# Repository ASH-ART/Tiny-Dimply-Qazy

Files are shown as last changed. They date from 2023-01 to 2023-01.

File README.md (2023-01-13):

# Tiny Dimply Qazy

A 10.5u 35% keyboard PCB. A tribute to Lazydesigner's Dimple, and tominabox1 and whydobearsexplod's QAZ.

## Status
WIP; awaiting second round of prototyping.

## Layout
KLE preview
<a href="http://www.keyboard-layout-editor.com/#/gists/85e2e431b75c7d8e9e7332ab9f5636bb">Link<a>
  
## Renders
Top view
Bottom view

## Specs
* STM32 F072 MCU
* JST SH or Molex EZMate Pico headers
* ESD and overcurrent protection
* Meme cut
* Other stuff like diodes (the cool ones)

## Todo
- [x] Confirm prototype works electronically
- [ ] QoL improvements and case fit
- [ ] Generic silk with revision number
- [ ] Misc. cleanups
- [ ] A la carte gerbers for connector options (JST or EZMate)
- [ ] Use git submodule for parts lib

## Disclaimer

This PCB has been tested to work _electronically_, but requires further prototyping for fit and usability. The members of the PCB development team are not liable if you end up with a non-functional pcb. Order at your own risk. Support will not be provided but pull requests will be reviewed and possibly accepted.

## License

This project is released under the GPL v3 License. Please refer to the LICENCE file.
  
## Credits
  
PeppyToad for the layout and pcb help and firmware, ash for the scuffed pcb, lazydesigner, tominabox1, whydobearsexplod and Alas for the inspiration.
Consider bhj

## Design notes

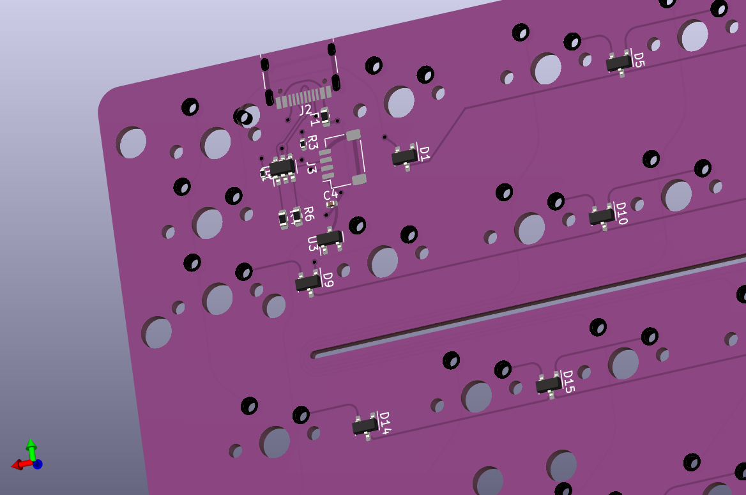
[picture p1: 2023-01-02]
Exports/Tiny Dimply Qazy PCB Render.png

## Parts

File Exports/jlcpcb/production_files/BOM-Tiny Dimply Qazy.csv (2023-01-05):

Comment | Designator | Footprint | LCSC
Polyfuse_Small | F1 | Fuse_0603_1608Metric | C10677
SMF9.0CA | D_PWR1 | D_SOD-123 | C123799
100n | C_VDD1,C_VDDIO2 | C_0603_1608Metric | C14663
1u | C_VDDA2 | C_0603_1608Metric | C15849
4.7u | C_VDD2,C_VDDIO1 | C_0603_1608Metric | C19666
10u | C_VDDA1 | C_0603_1608Metric | C19702
1.5k | R_USB1 | R_0603_1608Metric | C22843
4.7uF | C1 | C_0402_1005Metric | C23733
BAV70 | D1,D10,D11,D12,D13,D14,D15,D16,D17,D18,D19,D2,D20,D3,D4,D5,D6,D7,D8,D9 | SOT-23 | C2501
100k | R2 | R_0402_1005Metric | C25741
10k | R1,R3 | R_0402_1005Metric | C25744
USB_C_Receptacle_USB2.0 | J2 | USB_C_Receptacle_HRO_TYPE-C-31-M-12 | C2765186
USBLC6-2SC6 | U3 | SOT-23-6 | C2827654
Conn_01x04_Male | J1 | JST_SH_SM04B-SRSS-TB_1x04-1MP_P1.00mm_Horizontal | C2845363
B/R | SW1 | SW_SPST_TL3342 | C318884
470nF | C2 | C_0402_1005Metric | C47339
1uF | C3,C4 | C_0402_1005Metric | C52923
XC6206PxxxMR-Regulator_Linear | U2 | SOT-23 | C5446
Conn_01x04_Male | J3 | Molex_Pico-EZmate_78171-0004_1x04-1MP_P1.20mm_Vertical | C588524
STM32F072CBTx | U1 | LQFP-48_7x7mm_P0.5mm | C81720
5k1 | R4,R5 | R_0603_1608Metric | C83063
2N7002 | Q1 | SOT-23 | C8545
MX-NoLED | MX22 | MXOnly-1U-NoLED
MX-NoLED | MX39 | MXOnly-1.5U-NoLED
MX-NoLED | MX33 | MXOnly-1U-NoLED
MX-NoLED | MX20 | MXOnly-6U-Centered-ReversedStabilizers-NoLED
MX-NoLED | MX29 | MXOnly-1U-NoLED
MX-NoLED | MX25 | MXOnly-1.75U-NoLED
MX-NoLED | MX23 | MXOnly-1U-NoLED
MX-NoLED | MX43 | MXOnly-1.25U-NoLED
MX-NoLED | MX1 | MXOnly-1.5U-NoLED
MX-NoLED | MX6 | MXOnly-1U-NoLED
MX-NoLED | MX3 | MXOnly-1U-NoLED
MX-NoLED | MX31 | MXOnly-1U-NoLED
MX-NoLED | MX14 | MXOnly-3U-ReversedStabilizers-NoLED
MX-NoLED | MX40 | MXOnly-1U-NoLED
MX-NoLED | MX5 | MXOnly-1.75U-NoLED
MX-NoLED | MX24 | MXOnly-3U-ReversedStabilizers-NoLED
MX-NoLED | MX9 | MXOnly-1.25U-NoLED
MX-NoLED | MX37 | MXOnly-1U-NoLED
MX-NoLED | MX19 | MXOnly-7U-ReversedStabilizers-NoLED
MX-NoLED | MX16 | MXOnly-1U-NoLED
MX-NoLED | MX38 | MXOnly-1U-NoLED
MX-NoLED | MX17 | MXOnly-1U-NoLED
MX-NoLED | MX12 | MXOnly-1U-NoLED
MX-NoLED | MX34 | MXOnly-1U-NoLED
MX-NoLED | MX36 | MXOnly-1.25U-NoLED
MX-NoLED | MX30 | MXOnly-1U-NoLED
MX-NoLED | MX41 | MXOnly-1.5U-NoLED
MX-NoLED | MX11 | MXOnly-1U-NoLED
MX-NoLED | MX13 | MXOnly-1.25U-NoLED
MX-NoLED | MX15 | MXOnly-1.75U-NoLED
MX-NoLED | MX28 | MXOnly-1U-NoLED
MX-NoLED | MX21 | MXOnly-1U-NoLED
MX-NoLED | MX35 | MXOnly-1U-NoLED
MX-NoLED | MX2 | MXOnly-1U-NoLED
MX-NoLED | MX7 | MXOnly-1U-NoLED
MX-NoLED | MX44 | MXOnly-1.75U-NoLED
MX-NoLED | MX42 | MXOnly-ISO
MX-NoLED | MX32 | MXOnly-1U-NoLED
MX-NoLED | MX18 | MXOnly-1U-NoLED
MX-NoLED | MX10 | MXOnly-1U-NoLED
MX-NoLED | MX8 | MXOnly-1U-NoLED
MX-NoLED | MX4 | MXOnly-1.25U-NoLED
MX-NoLED | MX26 | MXOnly-1U-NoLED
MX-NoLED | MX27 | MXOnly-1U-NoLED

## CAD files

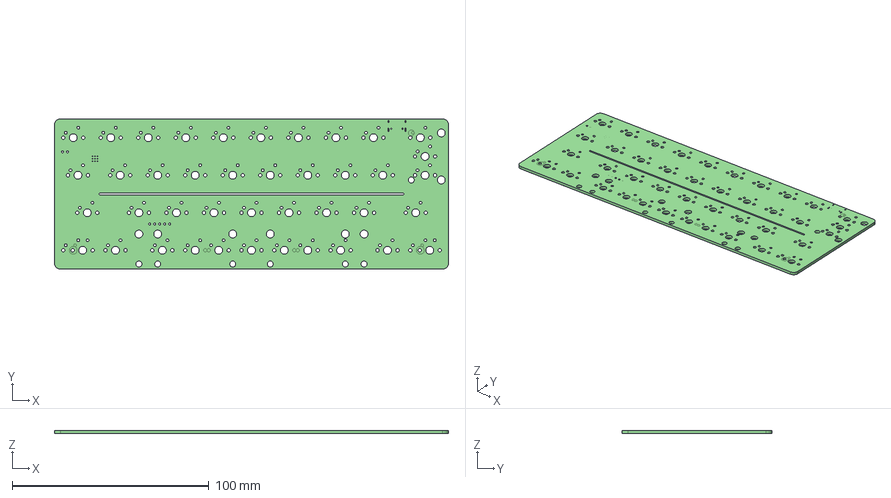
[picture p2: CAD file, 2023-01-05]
Exports/Tiny Dimply Qazy STEP Export.step
200.0 x 76.2 x 1.60 mm

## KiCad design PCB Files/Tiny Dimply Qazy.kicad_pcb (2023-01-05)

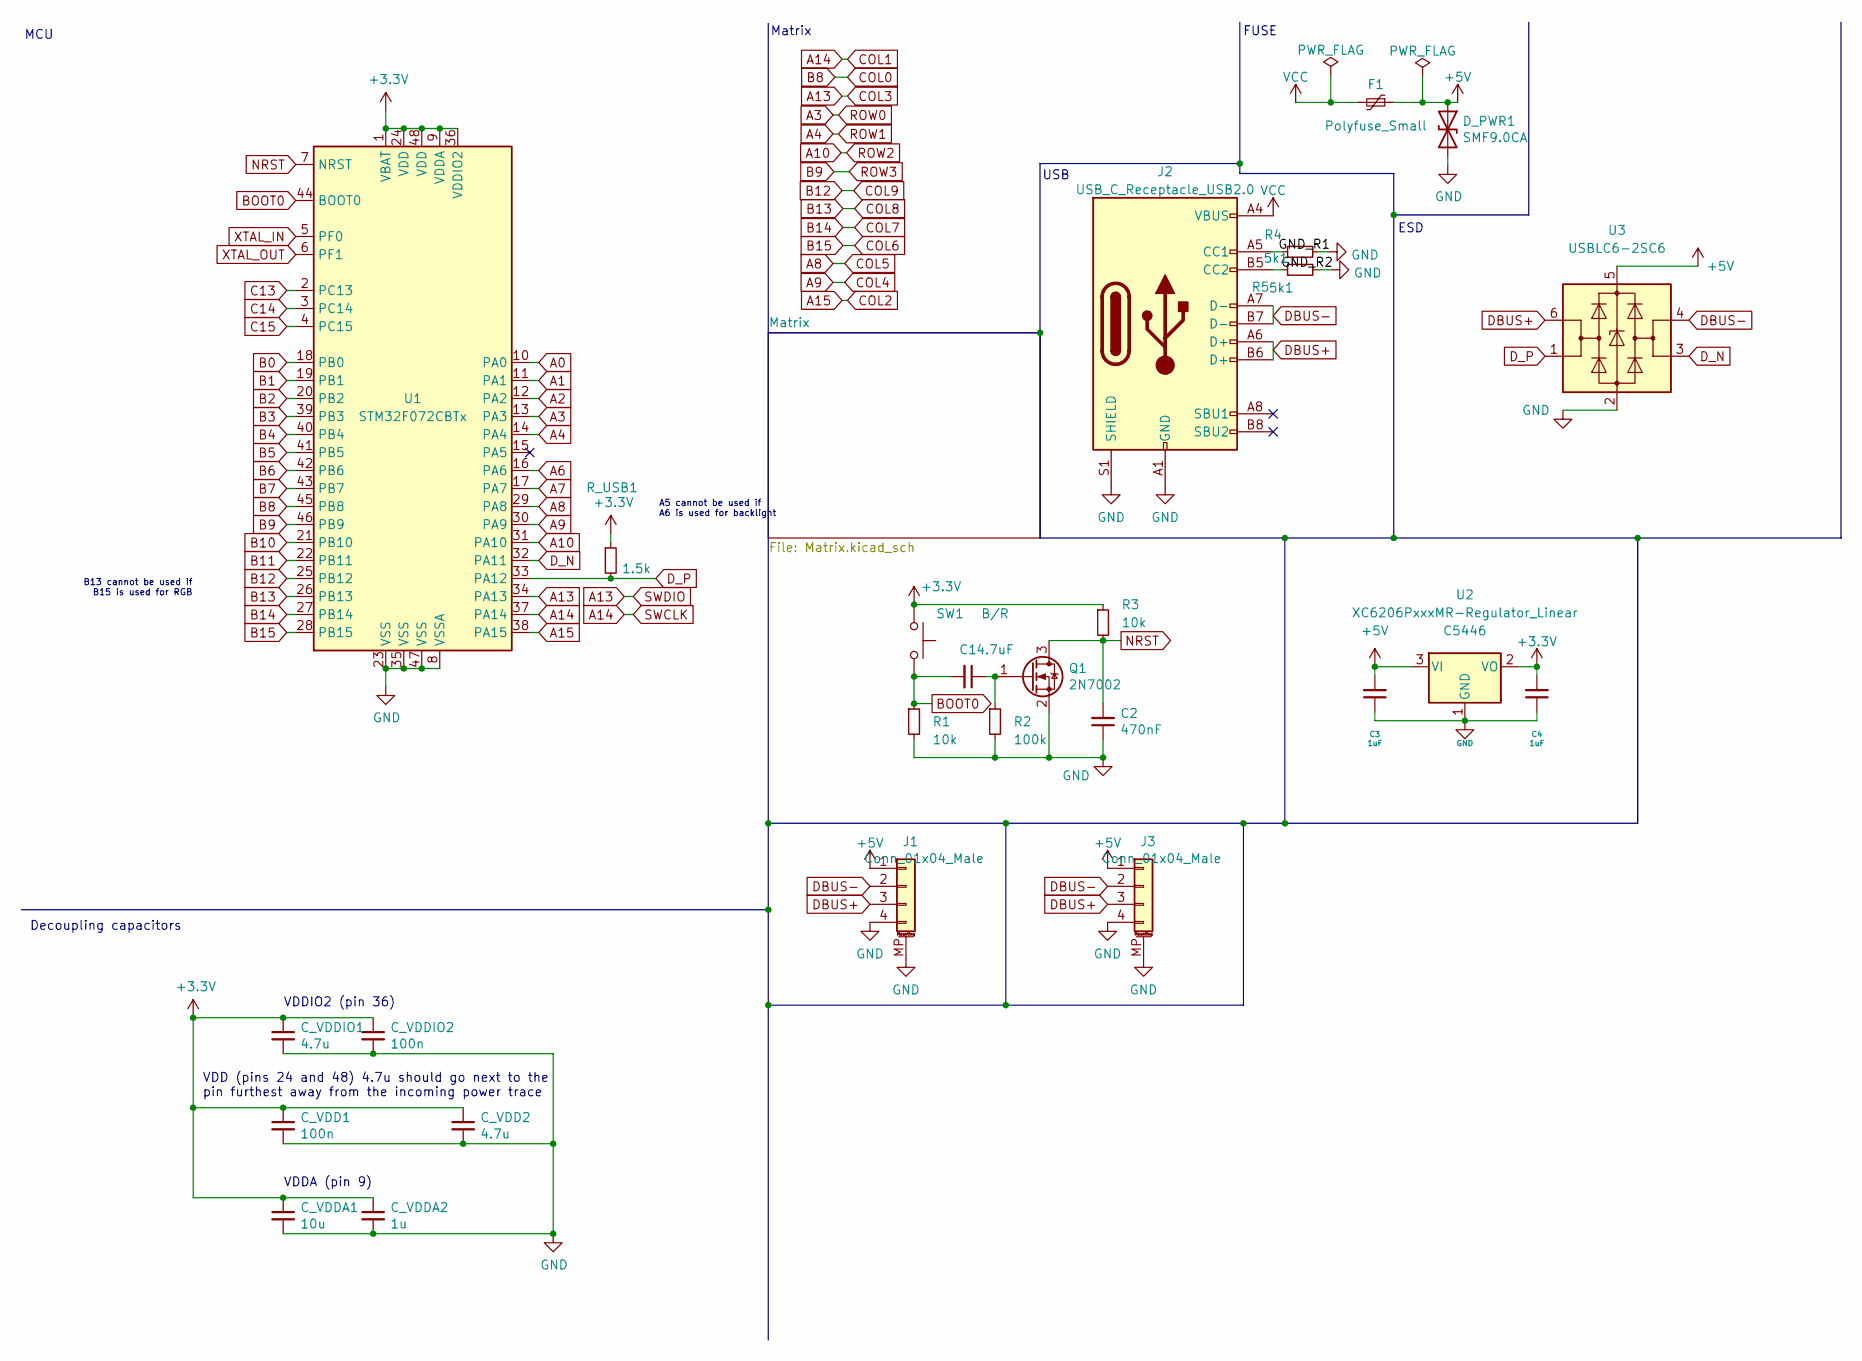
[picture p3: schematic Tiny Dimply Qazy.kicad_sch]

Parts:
C1: 4.7uF; C_0402_1005Metric; LCSC C23733
C2: 470nF; C_0402_1005Metric; LCSC C47339
C3, C4: 1uF; C_0402_1005Metric; LCSC C52923
C_VDD1: 100n; C_0603_1608Metric
C_VDD2: 4.7u; C_0603_1608Metric
C_VDDA1: 10u; C_0603_1608Metric
C_VDDA2: 1u; C_0603_1608Metric
C_VDDIO1: 4.7u; C_0603_1608Metric
C_VDDIO2: 100n; C_0603_1608Metric
D_PWR1: SMF9.0CA; D_SOD-123
F1: Polyfuse_Small; Fuse_0603_1608Metric
J1: Conn_01x04_Male; JST_SH_SM04B-SRSS-TB_1x04-1MP_P1.00mm_Horizontal
J2: USB_C_Receptacle_USB2.0; USB_C_Receptacle_HRO_TYPE-C-31-M-12
J3: Conn_01x04_Male; Molex_Pico-EZmate_78171-0004_1x04-1MP_P1.20mm_Vertical
Q1: 2N7002; SOT-23; LCSC C8545
R1, R3: 10k; R_0402_1005Metric; LCSC C25744
R2: 100k; R_0402_1005Metric; LCSC C25741
R4, R5: 5k1; R_0603_1608Metric
R_USB1: 1.5k; R_0603_1608Metric
SW1: B/R; SW_SPST_TL3342; LCSC C318884
U1: STM32F072CBTx; LQFP-48_7x7mm_P0.5mm
U2: XC6206PxxxMR-Regulator_Linear; SOT-23; LCSC C5446
U3: USBLC6-2SC6; SOT-23-6; LCSC C2827654

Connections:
+3V3: C4.2, C_VDD1.1, C_VDD2.1, C_VDDA1.1, C_VDDA2.1, C_VDDIO1.1, C_VDDIO2.1, R3.1, R_USB1.1, SW1.1, U1.1 (VBAT), U1.9 (VDDA), U1.24 (VDD), U1.36 (VDDIO2), U1.48 (VDD), U2.2 (VO)
+5V: C3.2, D_PWR1.1 (A1), F1.1, J1.1, J3.1, U2.3 (VI), U3.5 (VBUS)
/GND_R1: J2.A5 (CC1), R4.1
/GND_R2: J2.B5 (CC2), R5.1
A0: U1.10 (PA0)
A1: U1.11 (PA1)
A2: U1.12 (PA2)
A3: U1.13 (PA3); also elsewhere on the board
A4: U1.14 (PA4); also elsewhere on the board
A6: U1.16 (PA6)
A7: U1.17 (PA7)
A8: U1.29 (PA8); also elsewhere on the board
A9: U1.30 (PA9); also elsewhere on the board
A10: U1.31 (PA10); also elsewhere on the board
A13: U1.34 (PA13); also elsewhere on the board
A14: U1.37 (PA14); also elsewhere on the board
A15: U1.38 (PA15); also elsewhere on the board
B0: U1.18 (PB0)
B1: U1.19 (PB1)
B2: U1.20 (PB2)
B3: U1.39 (PB3)
B4: U1.40 (PB4)
B5: U1.41 (PB5)
B6: U1.42 (PB6)
B7: U1.43 (PB7)
B8: U1.45 (PB8); also elsewhere on the board
B9: U1.46 (PB9); also elsewhere on the board
B10: U1.21 (PB10)
B11: U1.22 (PB11)
B12: U1.25 (PB12); also elsewhere on the board
B13: U1.26 (PB13); also elsewhere on the board
B14: U1.27 (PB14); also elsewhere on the board
B15: U1.28 (PB15); also elsewhere on the board
BOOT0: C1.2, R1.1, SW1.2, U1.44 (BOOT0)
C13: U1.2 (PC13)
C14: U1.3 (PC14)
C15: U1.4 (PC15)
DBUS+: J1.3, J2.A6 (D+), J2.B6 (D+), J3.3, U3.6 (I/O1)
DBUS-: J1.2, J2.A7 (D-), J2.B7 (D-), J3.2, U3.4 (I/O2)
D_N: U1.32 (PA11), U3.3 (I/O2)
D_P: R_USB1.2, U1.33 (PA12), U3.1 (I/O1)
unnamed: C1.1, Q1.1 (G), R2.1
VCC: F1.2, J2.A4 (VBUS), J2.A9 (VBUS), J2.B4 (VBUS), J2.B9 (VBUS)
XTAL_IN: U1.5 (PF0)
XTAL_OUT: U1.6 (PF1)

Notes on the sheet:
A5 cannot be used if A6 is used for backlight
Decoupling capacitors
VDDIO2 (pin 36)
Matrix
USB
FUSE
MCU
ESD
B13 cannot be used if B15 is used for RGB
VDDA (pin 9)
VDD (pins 24 and 48) 4.7u should go next to the pin furthest away from the incoming power trace

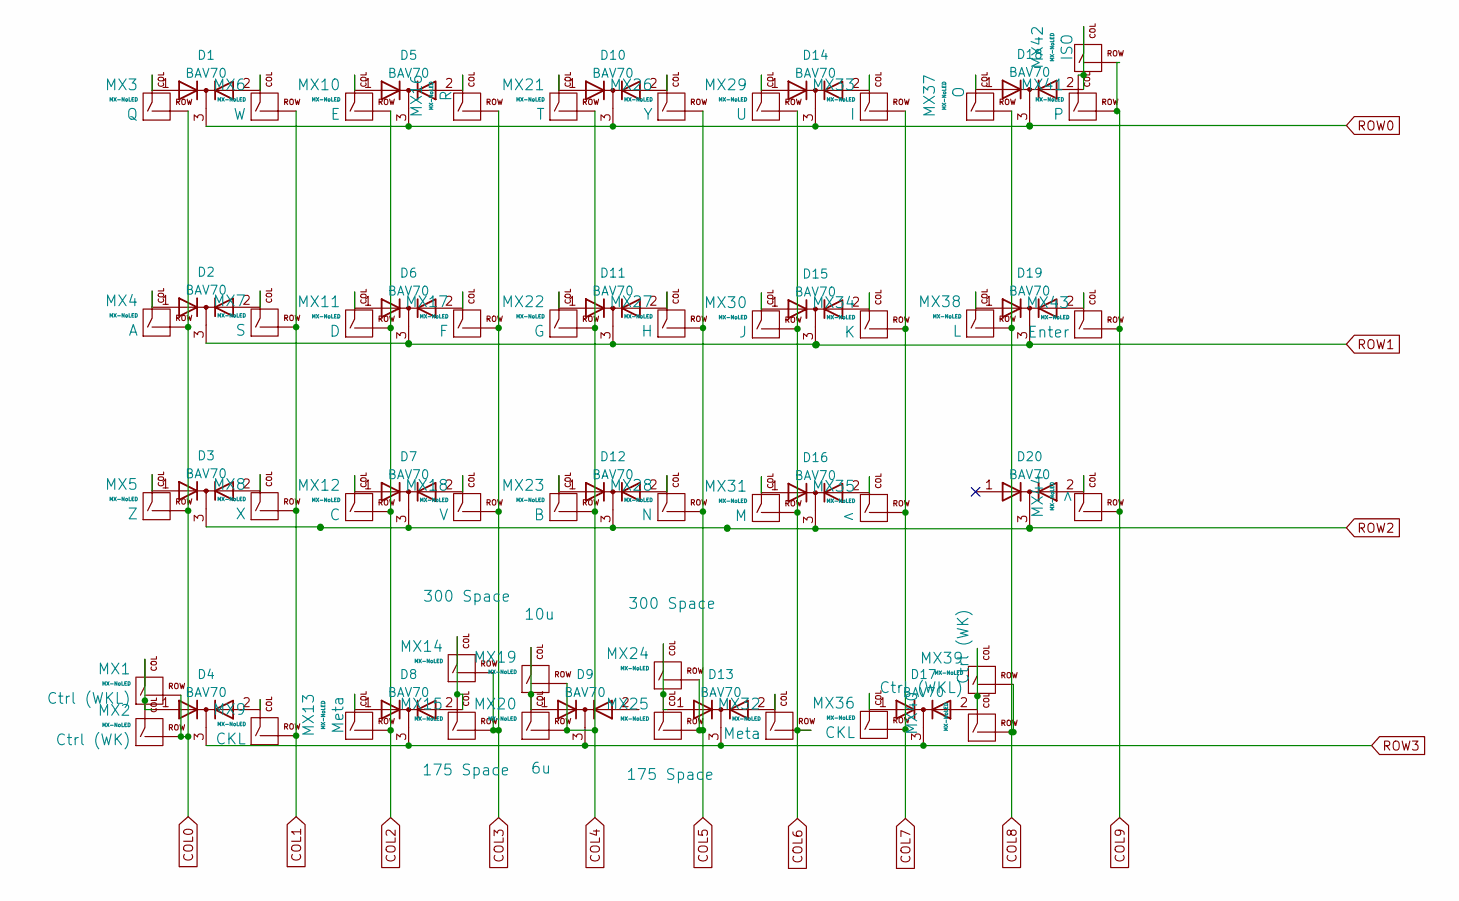
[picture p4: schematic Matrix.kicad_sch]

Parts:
D1, D2, D3, D4, D5, D6, D7, D8, D9, D10, D11, D12, D13, D14, D15, D16, D17, D18, D19, D20: BAV70; SOT-23
MX1, MX39, MX41: MX-NoLED; MXOnly-1.5U-NoLED
MX2, MX3, MX6, MX7, MX8, MX10, MX11, MX12, MX16, MX17, MX18, MX21, MX22, MX23, MX26, MX27, MX28, MX29, MX30, MX31, MX33, MX34, MX35, MX37, MX38, MX40: MX-NoLED; MXOnly-1U-NoLED
MX4, MX9, MX13, MX32, MX36, MX43: MX-NoLED; MXOnly-1.25U-NoLED
MX5, MX15, MX25, MX44: MX-NoLED; MXOnly-1.75U-NoLED
MX14, MX24: MX-NoLED; MXOnly-3U-ReversedStabilizers-NoLED
MX19: MX-NoLED; MXOnly-7U-ReversedStabilizers-NoLED
MX20: MX-NoLED; MXOnly-6U-Centered-ReversedStabilizers-NoLED
MX42: MX-NoLED; MXOnly-ISO

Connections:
A3: D1.3 (K), D5.3 (K), D10.3 (K), D14.3 (K), D18.3 (K); also elsewhere on the board
A4: D2.3 (K), D6.3 (K), D11.3 (K), D15.3 (K), D19.3 (K); also elsewhere on the board
A8: MX24.2 (ROW), MX25.2 (ROW), MX26.2 (ROW), MX27.2 (ROW), MX28.2 (ROW); also elsewhere on the board
A9: MX19.2 (ROW), MX20.2 (ROW), MX21.2 (ROW), MX22.2 (ROW), MX23.2 (ROW); also elsewhere on the board
A10: D3.3 (K), D7.3 (K), D12.3 (K), D16.3 (K), D20.3 (K); also elsewhere on the board
A13: MX14.2 (ROW), MX15.2 (ROW), MX16.2 (ROW), MX17.2 (ROW), MX18.2 (ROW); also elsewhere on the board
A14: MX6.2 (ROW), MX7.2 (ROW), MX8.2 (ROW), MX9.2 (ROW); also elsewhere on the board
A15: MX10.2 (ROW), MX11.2 (ROW), MX12.2 (ROW), MX13.2 (ROW); also elsewhere on the board
B8: MX1.2 (ROW), MX2.2 (ROW), MX3.2 (ROW), MX4.2 (ROW), MX5.2 (ROW); also elsewhere on the board
B9: D4.3 (K), D8.3 (K), D9.3 (K), D13.3 (K), D17.3 (K); also elsewhere on the board
B12: MX41.2 (ROW), MX42.2 (ROW), MX43.2 (ROW), MX44.2 (ROW); also elsewhere on the board
B13: MX37.2 (ROW), MX38.2 (ROW), MX39.2 (ROW), MX40.2 (ROW); also elsewhere on the board
B14: MX33.2 (ROW), MX34.2 (ROW), MX35.2 (ROW), MX36.2 (ROW); also elsewhere on the board
B15: MX29.2 (ROW), MX30.2 (ROW), MX31.2 (ROW), MX32.2 (ROW); also elsewhere on the board
unnamed: D1.1 (A), MX3.1 (COL)
unnamed: D1.2 (A), MX6.1 (COL)
unnamed: D2.1 (A), MX4.1 (COL)
unnamed: D2.2 (A), MX7.1 (COL)
unnamed: D3.1 (A), MX5.1 (COL)
unnamed: D3.2 (A), MX8.1 (COL)
unnamed: D4.1 (A), MX1.1 (COL), MX2.1 (COL)
unnamed: D4.2 (A), MX9.1 (COL)
unnamed: D5.1 (A), MX10.1 (COL)
unnamed: D5.2 (A), MX16.1 (COL)
unnamed: D6.1 (A), MX11.1 (COL)
unnamed: D6.2 (A), MX17.1 (COL)
unnamed: D7.1 (A), MX12.1 (COL)
unnamed: D7.2 (A), MX18.1 (COL)
unnamed: D8.1 (A), MX13.1 (COL)
unnamed: D8.2 (A), MX14.1 (COL), MX15.1 (COL)
unnamed: D9.1 (A), MX19.1 (COL), MX20.1 (COL)
unnamed: D10.1 (A), MX21.1 (COL)
unnamed: D10.2 (A), MX26.1 (COL)
unnamed: D11.1 (A), MX22.1 (COL)
unnamed: D11.2 (A), MX27.1 (COL)
unnamed: D12.1 (A), MX23.1 (COL)
unnamed: D12.2 (A), MX28.1 (COL)
unnamed: D13.1 (A), MX24.1 (COL), MX25.1 (COL)
unnamed: D13.2 (A), MX32.1 (COL)
unnamed: D14.1 (A), MX29.1 (COL)
unnamed: D14.2 (A), MX33.1 (COL)
unnamed: D15.1 (A), MX30.1 (COL)
unnamed: D15.2 (A), MX34.1 (COL)
unnamed: D16.1 (A), MX31.1 (COL)
unnamed: D16.2 (A), MX35.1 (COL)
unnamed: D17.1 (A), MX36.1 (COL)
unnamed: D17.2 (A), MX39.1 (COL), MX40.1 (COL)
unnamed: D18.1 (A), MX37.1 (COL)
unnamed: D18.2 (A), MX41.1 (COL), MX42.1 (COL)
unnamed: D19.1 (A), MX38.1 (COL)
unnamed: D19.2 (A), MX43.1 (COL)
unnamed: D20.2 (A), MX44.1 (COL)

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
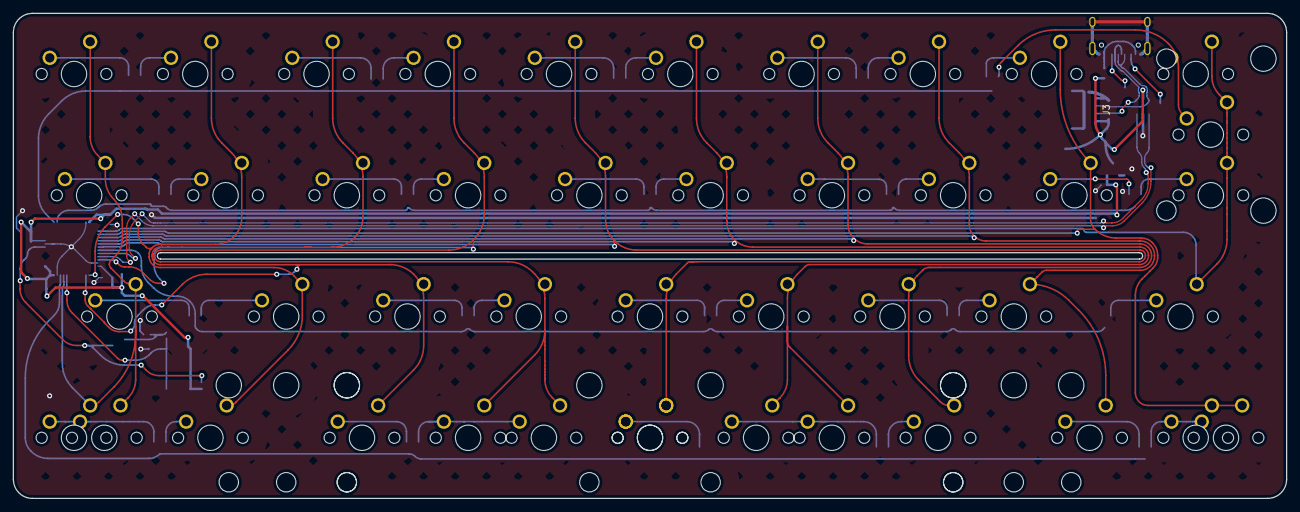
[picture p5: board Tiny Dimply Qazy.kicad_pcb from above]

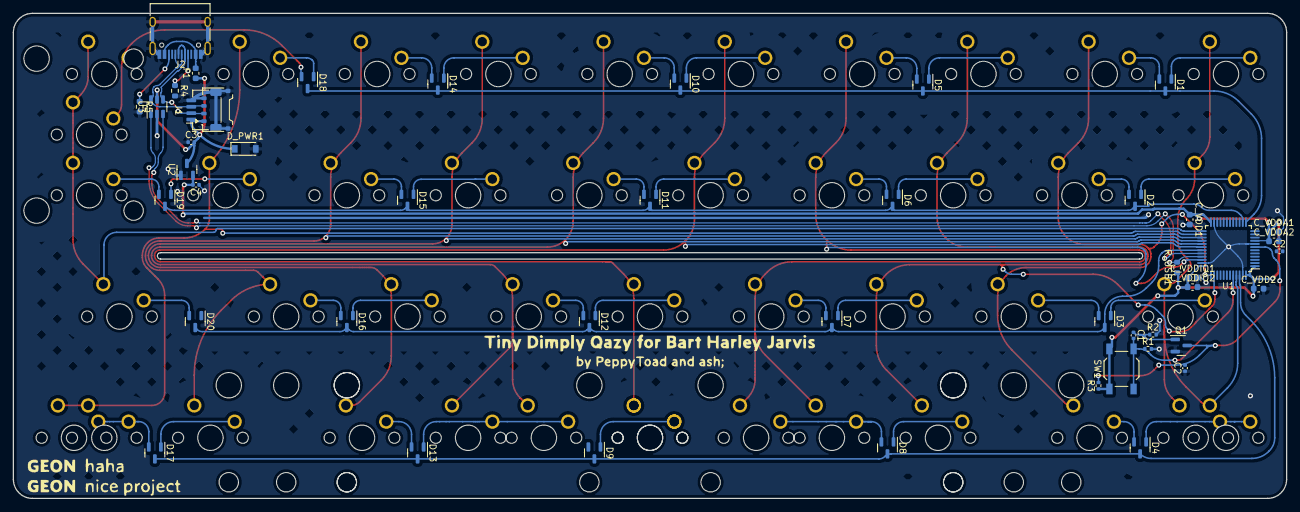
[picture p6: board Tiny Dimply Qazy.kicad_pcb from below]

Board: 2 copper layers, 200.0 x 76.2 mm, 92 parts (48 on the bottom side), 65 nets.

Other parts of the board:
C2#2: 470nF; C_0402_1005Metric
Geon: LOGO

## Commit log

2023-01-02 Initial Commit (adding export files)
    [BOM-PeppyQAZ.csv, Tiny Dimply Qazy STEP Export.step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]
2023-01-02 Initial Commit (adding readme and PCB files)
    [Matrix.kicad_sch, Tiny Dimply Qazy.kicad_pcb, Tiny Dimply Qazy.kicad_sch]
2023-01-02 Delete PCB Files/RP2040_minimal.pretty directory
    The PCB uses an STM MCU and therefore doesn't need the RP2040 library. This is to reduce bloat in the repo
2023-01-02 Delete MCU_RaspberryPi_RP2040.lib
    Same as previous commit (footprint not needed)
2023-01-05 Set line endings to LF
    [BOM-PeppyQAZ.csv, Matrix.kicad_sch, Tiny Dimply Qazy STEP Export.step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]
2023-01-05 Add prototype production changes
    * R4, R5 to 0603 (as requested during prototype PCBA)
    * Replace C_VDD2 with C_VDD3
    * Add missing ground connections for R1, R2
    * Move silk texts to the back
    * Centered big silk text
    * Add Molex EZMate Pico 4-pin header close to the JST SH header
    [BOM-Tiny Dimply Qazy.csv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]
2023-01-05 Change MX32 to 1.25U in the schematic
    No real changes to production files
    [Matrix.kicad_sch, Tiny Dimply Qazy.kicad_pcb, Tiny Dimply Qazy.kicad_sch]
2023-01-05 Rename Exports/Production files/ -> Exports/jlcpcb/
    [BOM-Tiny Dimply Qazy.csv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]
2023-01-05 Cleanup the schematics and add a library for smaller bav70s
    [Matrix.kicad_sch, Tiny Dimply Qazy.kicad_sch]
